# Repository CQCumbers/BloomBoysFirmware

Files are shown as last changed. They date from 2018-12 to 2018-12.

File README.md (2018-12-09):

# Bloom Boys
> Collect dissolved oxygen depth profiles

This code was written for a first year college engineering project with 4 other students. It runs on a Particle Photon and enables automatic collection of dissolved oxygen depth profiles by controlling a winch, reading DO concentration from a probe, and sending measurements to a cloud database. The prototype was deployed in Barton Pond, Ann Arbor's drinking water source, and the data it gathers will hopefully allow for better local prediction of algal blooms and lake overturn. It uses I2C to communicate with the probe, and a quadrature encoder to reliably position it at certain depths. To store and visualize data, this system also depends on a cloud server with InfluxDB and Grafana.

## Architecture Diagram

diagram

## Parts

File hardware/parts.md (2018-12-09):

# Parts List

- Particle Photon
- DC power adapter
- DC gearmotor with rotary encoder
- MonkMakes Phobot
- 30" Male-Female BNC extension cord
- PG-7 cable glands
- 3D printed PLA parts
- Atlas Scientific DO Sensor Kit
- 1.75" ID U-bolts
- 8-32 0.5" screws & heat-set inserts
- Nylon rope and weights

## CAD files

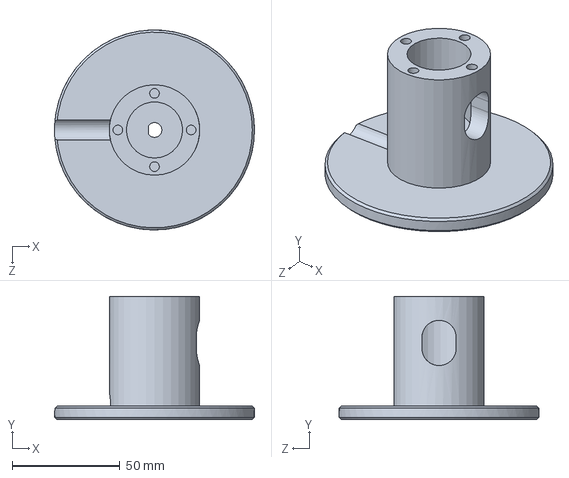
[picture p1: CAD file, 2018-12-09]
hardware/Spool1.SLDPRT
92.7 x 57.1 x 92.7 mm

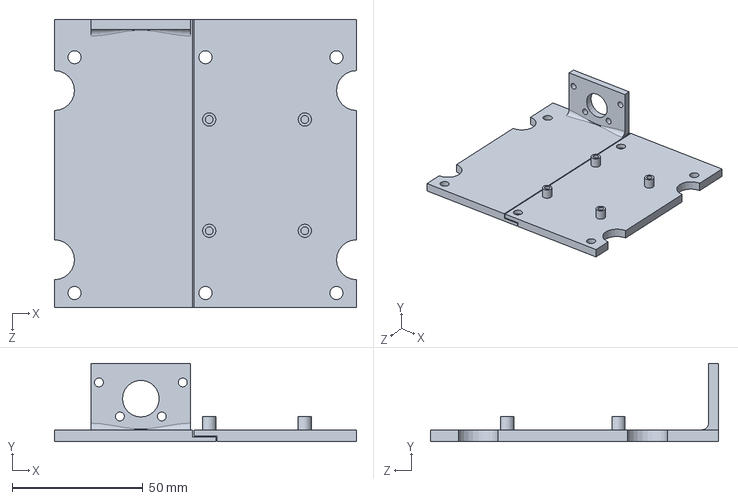
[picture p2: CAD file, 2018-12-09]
hardware/Plate1.SLDPRT
115.3 x 30.0 x 110.0 mm

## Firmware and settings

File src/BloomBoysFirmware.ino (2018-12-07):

/*
 * BloomBoysFirmware
 * Firmware for dissolved oxygen depth profile sensor
 */

#include "motor.h"
#include "sensor.h"
#include "influx.h"
#include "config.h"

// sampling depths in feet
const int numDepths = 4;
float depthsFeet[numDepths] = {5, 10, 15, 20};
int depths[numDepths];
// samping frequency in seconds
unsigned freq = 120;

// global variables
Motor motor(4, D3);
Sensor sensor(97);
Client client(
  INFLUX_HOST, 8086, "BLOOMBOYS",
  INFLUX_USER, INFLUX_PASSWORD
);
float measurements[numDepths];
unsigned nextProfile = 0;

// setup serial & register cloud functions
void setup() {
  Serial.begin(9600);
  for (int i = 0; i < numDepths; ++i)
    depths[i] = depthsFeet[i] * motor.clicksPerFeet;
  // use D5 as encoder Vcc
  pinMode(D5, OUTPUT);
  pinSetFast(D5);
}

// collect & send depth profile data repeatedly
void loop() {
  unsigned now = Time.now();
  if (now < nextProfile) return;
  nextProfile = now + freq;
  profile();
}

// collect depth profile
void profile() {
  for (int i = 0; i < numDepths; ++i) {
    motor.runTo(depths[i]);
    measurements[i] = sensor.measure();
  }
  db.send(numDepths, depthsFeet, measurements);
  motor.runTo(0);
}

// print profile to serial
void show() {
  Serial.print("\n" + Time.timeStr(nextProfile - freq) + "\n");
  Serial.print("Depth (ft): DO (mg/L)\n");
  Serial.print("-----------------------\n");
  for (int i = 0; i < numDepths; ++i) {
    Serial.printf("%10f: %9f\n", depthsFeet[i], measurements[i]);
  }
}

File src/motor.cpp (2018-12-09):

#include "motor.h"
#include "Particle.h"

Motor::Motor(int motor, int enc_in): encoder(enc_in) {
  phobot = PhoBot(5.0, 6.0);
  stop = "M" + String(motor) + "-S";
  forward = "M" + String(motor) + "-F-100";
  backward = "M" + String(motor) + "-B-100";

  // second encoder doesn't work on our hardware :(
  pinMode(encoder, INPUT);
  attachInterrupt(encoder, &Motor::interrupt, this, CHANGE);
}

void Motor::interrupt() {
  pos += direction;
  // brake slightly ahead of time
  if (pos + direction * 35 != stop_pos)
    return;
  phobot.setMotors(stop);
  running = false;
}

// run motor to (possibly past) encoder pos
void Motor::runTo(int pos_in) {
  stop_pos = pos_in;
  if (pos_in > pos + 35) {
    phobot.setMotors(forward);
    direction = 1;
    running = true;
  } else if (pos_in < pos - 35) {
    phobot.setMotors(backward);
    direction = -1;
    running = true;
  }
  while (running)
    Particle.process();
}

// stop motor & reset position
void Motor::setPos(int pos_in) {
  phobot.setMotors(stop);
  running = false;
  pos = pos_in;
  stop_pos = pos_in;
}

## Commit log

2018-11-27 Add 3D model, modify code to work with defective encoder
    [Spool1.SLDPRT]
2018-12-09 Organize files, add diagram
    [Plate1.SLDPRT, Spool1.SLDPRT]
